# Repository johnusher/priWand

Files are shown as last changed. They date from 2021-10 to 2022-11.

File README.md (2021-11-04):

# priWand

# johnusher/priWand Summary

Private Repo! <br />
This repo is for the wand project. <br />

Mesh network between multiple Raspis for a nice game of Wand.

A webserver on the pi provides a bi-directional UI.

## Hardware set-up

Tested with Pi 4, 3B, Zero (they have the same GPIO pin out)

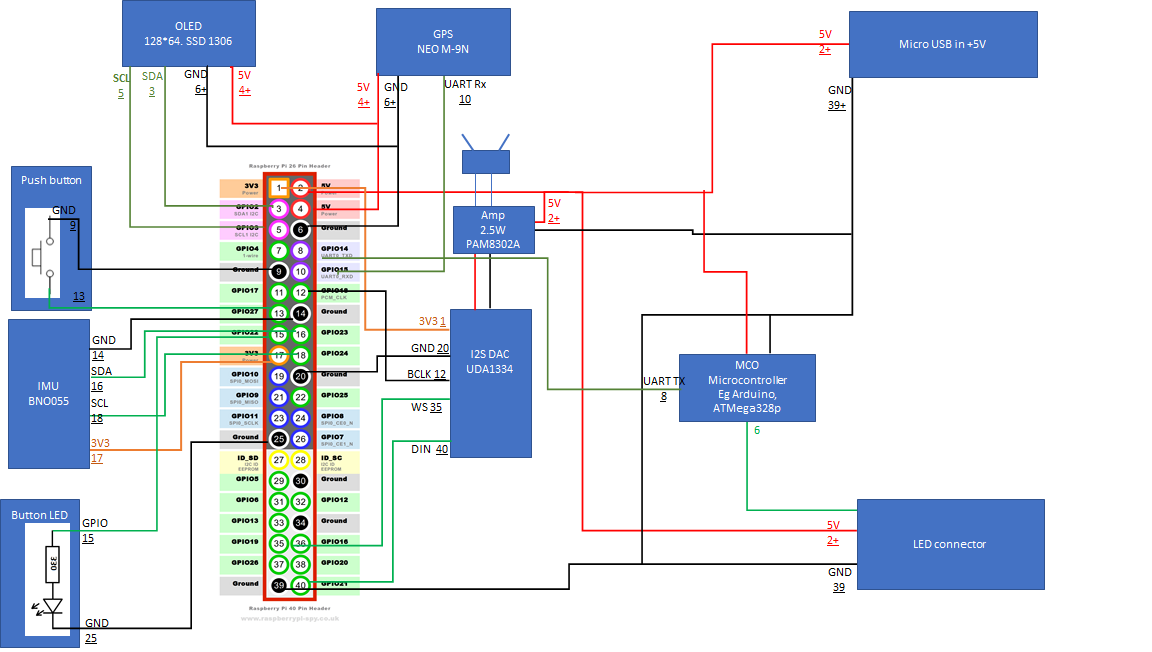
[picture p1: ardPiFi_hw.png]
HardWare


See [shopping list section](#hardware-shopping-list) for details on components. 

### MCU for programmable LEDs 
ATmega328p- Arduino Nano. MCU and NeoPixelLED strips should be powered separately.

### GPS
GPS module connect with GPIO serial. It shows up at serial port /dev/ttyS0. In raspi-config settings, you  need to disable serial console output, enable Hardware serial, and maybe disable bluetooth. 

Tested using the UBLOX NEO-6M (GPS only= less accurate) and NEO M-9N (GPS, GLONASS, Galileo = more accurate).

Note we only use serial Rx from GPS module into the Raspi, as we use Serial Tx for Arduino MCU.

NEO M-9N default 38000 baud UART, but changed to 9600 and poll every 2 seconds. To do this this, use u-center 21.02 (windows only), or use NEO9Settings.txt configuration script with ubxconfig.sh from https://gist.github.com/hdoverobinson/42732da4c5b50d031f60c1fae39f0720)  (untested and won't work without serial Tx from Raspi)

```bash
./ubxconfig.sh /dev/ttyS0 NEO9Settings.txt
```

Useful GPS:
```bash
go run gps/test_GPS2.go 
```

Prints Lat-Long cooridinates and HDOP.<br />
where HDOP:<br />
<1	Ideal	Highest possible confidence level to be used for applications demanding the highest possible precision at all times.<br />
1-2	Excellent	At this confidence level, positional measurements are considered accurate enough to meet all but the most sensitive applications.<br />
2-5	Good	Represents a level that marks the minimum appropriate for making accurate decisions. Positional measurements could be used to make reliable in-route navigation suggestions to the user.<br />
5-10	Moderate	Positional measurements could be used for calculations, but the fix quality could still be improved. A more open view of the sky is recommended.<br />

Read raw NMEA format GPS data from serial port
```bash
cat -A /dev/ttyUSB0
```

Write raw NMEA format data to file
```bash
cat </dev/ttyUSB0 > gpsdata.txt
```

Convert NMEA file to Google-maps kml, discard low-HDOP data that is not "excellent quality", dude.
```bash
gpsbabel -i nmea -f gpsdata.txt -x discard,hdop=1,sat=9  -o kml -F outfile.kml
```

### Audio: I2S

Raspi Zero does not have audio IO, so output is I2S into a 2 W amp, and then to a loudspeaker.

Install port audio and make I2s default:
```bash
sudo apt-get install libasound-dev portaudio19-dev libportaudio2 libportaudiocpp0 mpg123 
curl -sS https://raw.githubusercontent.com/adafruit/Raspberry-Pi-Installer-Scripts/master/i2samp.sh | bash
```
reboot.

Test audio works:

```bash
sudo speaker-test -c2 
sudo mpg123 -b 1024 http://ice1.somafm.com/u80s-128-mp3
```
to generate white noise out of the speaker, alternating left and right.

There is no built-in audio out with the Pi-Zero, so we use an I2S audio DAC: UDA1334.

from https://learn.adafruit.com/adafruit-i2s-stereo-decoder-uda1334a/raspberry-pi-wiring

Optional to remove ALSA errors:<br />
sudo vi /usr/share/alsa/alsa.conf to change pcm.front cards.pcm.front -> pcm.front cards.pcm.default<br />
Use the file alsa.conf in the git repo.

sudo apt-get --no-install-recommends install jackd2

### GPIO: Button and LED

A push button attaches to GPIO27=  pin 13, and an LED with 330 Ohm series resistor to GPIO22 =  pin 15.

GPIO support not intalled for Raspi Lite so run this:
```bash
sudo apt-get install wiringpi
gpio readall
```

on pi 4, try the following:

```bash
cd /tmp
wget https://project-downloads.drogon.net/wiringpi-latest.deb
sudo dpkg -i wiringpi-latest.deb
```

test button LED works:
```bash
gpio -g mode 22 out
gpio -g write 22 1
 ``` 
 
run this command to set pullup:
```bash
raspi-gpio set 27 pu
```

when you run
gpio readall
you should see following when button not pressed 
```bash
BCM| wPi |   Name  | Mode | V
27 |   2 | GPIO. 2 |   IN | 1 
```
```bash
27 |   2 | GPIO. 2 |   IN | 0
```
when pressed 

To test GPIO is working, run test_GPIO2.go (you will need I2S connected for audio)
```bash
run test_GPIO2.go
```

### Display screen
OLED 128*64.

Power with +5 V. OLED connects via I2C bus 1. SDA -> pin 3  SCL -> pin 5). 

### Inertial Measurement Unit (IMU)
Bosch BNO055:  triaxial accelerometer, gyroscope, geomagnetic sensor.

Power with +3.3 V.
connect BNO055 SDA to pin 16 and SCLK to pin 18.

I2c configure:

From https://github.com/kpeu3i/bno055/:

"it seems all versions of Raspberry Pi have an I²C bus hardware problem preventing them from working correctly with Bosch BNO055. The problem has been variously diagnosed as being due to the Pi’s inability to handle clock stretching in arbitrary parts of the I²C transaction and the BNO055 chip’s exquisite sensitivity to I²C bus levels."

Raspbian has a software I2C driver that can be enabled by adding the following line to /boot/config.txt:

dtoverlay=i2c-gpio,bus=3
This will create an I2C bus called /dev/i2c-3. SDA will be on GPIO23 and SCL will be on GPIO24 which are pins 16 and 18 on the GPIO header respectively.

SDA = pin 16, SCL = pin 18.

```bash
sudo tee --append /boot/config.txt > /dev/null << 'EOF'
dtoverlay=i2c-gpio,bus=3
EOF
```
++sudo reboot now

Check your I2c is set up correctly:

sudo apt-get install i2c-tools

sudo i2cdetect -l

You will now see that i2c bus 3 also listed. Also run:

sudo i2cdetect -y 1

This should show OLED on 3c

sudo i2cdetect -y 3

This should show the BNo055 on 28.

There are "no hardware" options for running the main Go file without these HW modules.

## WLAN dongle: 

Add USB dongle TP-Link TL-WN725N.

This messes up BATMAN as the dongle can go to WLAN0 or WLAN1.
To change this and make WLAN0 the built-in: see 

https://www.raspberrypi.org/forums/viewtopic.php?f=36&t=198946

1. switch off systemd-predictable mechanism stuff (unless done already):

```bash
sudo ln -nfs /dev/null /etc/systemd/network/99-default.link
  ```

  2. setup udev rules that uniquely identify your interfaces based on their USB connector positions:

```bash

vi /etc/udev/rules.d/72-wlan-geo-dependent.rules

#
# +---------------+
# | wlan1 | wlan1 |
# +-------+-------+
# | wlan1 | wlan1 |
# +---------------+ (RPI USB ports with position independent device names for a maximum of 1 optional wifi dongle)
# 
# | wlan0 | (onboard wifi)
#
ACTION=="add", SUBSYSTEM=="net", SUBSYSTEMS=="sdio", KERNELS=="mmc1:0001:1", NAME="wlan0"
ACTION=="add", SUBSYSTEM=="net", SUBSYSTEMS=="usb",  KERNELS=="1-1.2",       NAME="wlan1"
ACTION=="add", SUBSYSTEM=="net", SUBSYSTEMS=="usb",  KERNELS=="1-1.4",       NAME="wlan1"
ACTION=="add", SUBSYSTEM=="net", SUBSYSTEMS=="usb",  KERNELS=="1-1.3",       NAME="wlan1"
ACTION=="add", SUBSYSTEM=="net", SUBSYSTEMS=="usb",  KERNELS=="1-1.5",       NAME="wlan1"

 ```

NB

When running on WLAN1, we must force IP4 to access github.com as it does not support IP6

sudo dhclient -4 -v wlan1

or

```bash
sudo tee --append /etc/sysctl.conf > /dev/null << 'EOF'
net.ipv6.conf.all.disable_ipv6=1
EOF
 ```

echo sudo net.ipv6.conf.all.disable_ipv6=1 >> /etc/sysctl.conf

Install driver for tl-wn8725N

from:
https://www.raspberrypi.org/forums/viewtopic.php?p=462982#p462982
```bash
sudo wget http://downloads.fars-robotics.net/wifi-drivers/install-wifi -O /usr/bin/install-wifi
sudo chmod +x /usr/bin/install-wifi
sudo install-wifi
 ```
reboot

make sure you have added static ip to wlan 1:

```bash
sudo tee --append /etc/dhcpcd.conf > /dev/null << 'EOF'

# set static ip

interface wlan1
static ip_address=192.168.1.164/24
static routers=192.168.1.1
static domain_name_servers=192.168.1.1

EOF
 ```

after iwconfig
should see wlan0 and wlan connected to same ESSID with AP.

## Auto-start: 

Automatically load BATMAN ad the go script on boot.

To do this, we make a service. This runs on bootup, after the network is up. It runs runBATMAN.sh (or run runBATMAN2, runBATMAN3):

After 20 seconds, the BATMAN mesh network is generated, then the go app is run.

Thus, you need to make sure the app is pre-compiled,
ie
```bash
cd /home/pi/apl/
go build wand1.go
```

There are many ways to do this, but this one is mine. systemctl is not my best friend. For about an hour, it was my life. I do not care to master it.

1. cd ~/apl2

2. chmod 664 delayBoot2.service

3. sudo cp   delayBoot2.service  /etc/systemd/system/

4. sudo systemctl enable  delayBoot2

5. sudo systemd-analyze verify delayBoot2.service

To reload systemd with this new service unit file, run:
systemctl daemon-reload

To start the script on boot, enable the service with systemd:

6. sudo systemctl enable delayBoot2.service

useful:

sudo systemctl stop delayBoot2.service

sudo systemctl start delayBoot2.service

systemctl status delayBoot2.service

## Hardware shopping list

Rasperry Pi 3 Model B+ tested, Pi Zero WH, and Pi-4 B

MCU:
https://www.christians-shop.de/Nano-V3-developer-board-for-Arduino-IDE-ATMEL-ATmega328P-AVR-Microcontroller-CH340-Chip-Christians-Technikshop

https://www.amazon.de/-/en/gp/product/B078SBBST6/ref=ppx_yo_dt_b_asin_title_o02_s00?ie=UTF8&psc=1

GPS: uBlox NEO-6M :
https://www.amazon.de/dp/B088LR3488/ref=pe_3044161_185740101_TE_item

GPS: uBlox NEO-M9N :
https://tinyurl.com/j2476wb  (Banggood.com)

OLED display:
https://www.amazon.de/-/en/gp/product/B01L9GC470/ref=ppx_od_dt_b_asin_title_s00?ie=UTF8&psc=1

IMU Bosch BNO055:
https://www.amazon.de/-/en/gp/product/B072NLTPTJ/ref=ppx_yo_dt_b_asin_title_o01_s00?ie=UTF8&psc=1

BROgrammable LED strip WS2812:
https://www.mouser.de/ProductDetail/digilent/122-000/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

WLAN dongle TP-Link TL-WN725N:
https://www.amazon.de/gp/product/B008IFXQFU/ref=ppx_yo_dt_b_asin_title_o03_s00?ie=UTF8&psc=1

### OS

Install Raspi lite from onlione or try this:

1. Download Raspian Lite: https://downloads.raspberrypi.org/raspbian_lite_latest
2. Flash `20XX-XX-XX-raspbian-stretch-lite.zip` using Etcher
3. Remove/reinsert flash drive
4. Add `ssh` and `bootstrap` files:
    ```bash
    touch /Volumes/boot/ssh
    cp bin/bootstrap /Volumes/boot/
    chmod a+x /Volumes/boot/bootstrap
    diskutil umount /Volumes/boot
    ```

### First Boot

```bash
ssh pi@raspberrypi.local
# password: raspberry

# change default password
passwd

# set quiet boot
sudo sed -i '${s/$/ quiet loglevel=1/}' /boot/cmdline.txt

# install packages
sudo apt-get update
sudo apt-get install -y git tmux vim dnsmasq hostapd

# set up wifi (note leading space to avoid bash history)
sudo tee --append /etc/wpa_supplicant/wpa_supplicant.conf > /dev/null << 'EOF'
network={
    ssid="<WIFI_SSID>"
    psk="<WIFI_PASSWORD>"
}
EOF

# set static IP address
sudo tee --append /etc/dhcpcd.conf > /dev/null << 'EOF'

# set static ip

interface eth0
static ip_address=192.168.1.164/24
static routers=192.168.1.1
static domain_name_servers=192.168.1.1

interface wlan0
static ip_address=192.168.1.164/24
static routers=192.168.1.1
static domain_name_servers=192.168.1.1

EOF

if we have an additional wlan usb:

sudo tee --append /etc/dhcpcd.conf > /dev/null << 'EOF'

# set static ip

interface wlan1
static ip_address=192.168.1.164/24
static routers=192.168.1.1
static domain_name_servers=192.168.1.1

EOF

# reboot to connect over wifi
sudo shutdown -r now
```

```bash
# configure git
git config --global push.default simple
git config --global core.editor "vim"
git config --global user.email "you@example.com"
git config --global user.name "Your Name"

# disable services
sudo systemctl disable hciuart
sudo systemctl disable bluetooth
sudo systemctl disable plymouth

# remove unnecessary packages
sudo apt-get -y purge libx11-6 libgtk-3-common xkb-data lxde-icon-theme raspberrypi-artwork penguinspuzzle ntp plymouth*
sudo apt-get -y autoremove

sudo raspi-config nonint do_boot_behaviour B2 0
sudo raspi-config nonint do_boot_wait 1
sudo raspi-config nonint do_serial 1
```

# now you are setup! run bootstrap to download packages

Run Bootstrap from https://github.com/johnusher/ardpifi/tree/master/bin
./bootstrap
```

### Mesh network

NB need to runt his command twice!

On raspi #1 run

./runBATMAN.sh

On raspi #2 run

./runBATMAN2.sh

## Code

Note
All dependencies managed in `go.mod` now,
just add an import directive for any new depedency in your `*.go` files, and
`go run/build` should just handle it.

All code (and go) is installed via bootstrap.

# Arduino CLI install

follow instructions here:
https://siytek.com/arduino-cli-raspberry-pi/

this additional command was needed:
arduino-cli core install arduino:avr

Note the directory for the Duino project must have the same name as the main file .ino.

Tested with Duino Uno and Duino clone: "Nano V3 | ATMEL ATmega328P AVR Microcontroller | CH340-Chip".
The Uno shows on port ttyACM0 and the clone on ttyUSB.

## add libraries:

arduino-cli lib search Adafruit_NeoPixel

in duino_src:

compile and flash:
Uno:
arduino-cli compile --fqbn arduino:avr:uno duino_src

arduino-cli upload -p /dev/ttyACM0 --fqbn arduino:avr:uno duino_src

Clone

arduino-cli compile --fqbn arduino:avr:diecimila:cpu=atmega328 duino_src

arduino-cli upload -p /dev/ttyUSB0 --fqbn arduino:avr:diecimila:cpu=atmega328 duino_src

arduino-cli upload -p /dev/ttyACM0 --fqbn arduino:avr:diecimila:cpu=atmega328 duino_src

## Run

On raspi #1 run

```bash
./runBATMAN.sh
go run wand1.go -rasp-id=me --web-addr :8080 -log-level debug
```

On raspi #2 run

```bash
./runBATMAN2.sh
go run wand1.go -rasp-id=poo --web-addr :8081 -no-lcd -log-level debug.
```

Press any key, sent to mesh, and if it is a 0 or 1, we change led pattern.

To exit, press "q" to exit termbox, and then ctrl-c to exit the program.

### Flags

There are various flags if certain HW modules are not attached to the raspi:

```bash
$ go run wand1.go -h
  -log-level string
    	log level, must be one of: panic, fatal, error, warn, info, debug, trace (default "info")
  -no-batman
    	run without batman network
  -no-duino
    	run without arduino
  -no-gps
    	run without gps
  -no-acc
    	run without Bosch accelerometer      
  -no-oled
    	run without oled display      
  -no-oled
    	run without sound  
  -rasp-id string
    	unique raspberry pi ID (default "60"). Only 2 characters. Recomended to use last 2 digits of the device IP.
  -web-addr string
    	address to serve web on (default ":8080")
```

### Run without hardware

Run with hardware (serial, network) API calls mocked out:

```bash
go run wand1.go --rasp-id "raspi 1" --web-addr :8080 --no-batman --no-duino --no-gps --no-lcd --log-level debug
```

# Set up port forwarding for web server

## First-time ssh config setup

On laptop:

```bash
PI_IP=192.168.1.164
USER=pi

cat << EOF >> ~/.ssh/config

Host pi
  HostName $PI_IP
  User $USER
  Port 22
  BatchMode yes
  ServerAliveInterval 60
  ServerAliveCountMax 5
  ForwardAgent yes
    LocalForward 127.0.0.1:8080 127.0.0.1:8080
EOF
```

## Tunnel

```bash
ssh $USER@pi
```

Open a browser window to localhost:8080

## Main routines to run:

```bash
go build test_record_spell.go && sudo ./test_record_spell -no-sound
```
test_record_spell records MCU movement when we have a button press.

NB The GPIO channel can not close properly, so you may need to kill the app with

sudo ps aux | grep test_record_spell

kill -9 -1 3290 

## Other useful scripts
```bash
go run test_BNo055_save_data.go
```
NB not running!! This saves accelerometer and gyroscope data to a txt file.

```bash

go build test_GPIO.go && sudo ./test_GPIO

```
NV this currently fails! This reads the button, debounces, and plays sound when we have button down.

```bash
go run OLEDtest.go
```
This displays a real-time clock on the OLED.

```bash
go run test_quats_64_to_py_tf.go
```
process quat recordings with TF... this tests if you have python and go correctly installed.

```bash
go run test_parse_quats_oled.go
```
test_parse_quats_oled

convAccData.m

MATLAB script to process accelerometer data.

# thanks 

@siggy!

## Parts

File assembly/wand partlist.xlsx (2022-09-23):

item | cost |  | order
loudspeaker | 2.6 | x | for 2. https://www.berrybase.de/raspberry-pi/raspberry-pi-computer/displays/8-ohm-5w-lautsprecher-passend-f-252-r-waveshare-displays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
audio amp | 4.05 |  | https://www.berrybase.de/sensoren-module/audio-schall/adafruit-mono-2.5w-class-d-audio-verst-228-rker-pam8302
small button+LED | 3.95 | x | https://www.amazon.de/-/en/gp/product/B07SR4S6MS/ref=ewc_pr_img_1?smid=A3B8GCWPRWBH74&psc=1
Pi Zero | 11.13 | g
ATmega328p | 3.7 | g
OLED | 6.99 |  | https://www.az-delivery.de/en/products/0-96zolldisplay
GPS |  | g
IMU | 34.16 |  | https://www.exp-tech.de/sensoren/magnet/8435/bluedot-bno055-9-axis-imu
PLED | 5 |  | https://www.led-genial.de/Power-Dot-3W-WS2811-kompatibel
I2S Audio | 7.15 |  | https://www.berrybase.de/sensoren-module/audio-schall/adafruit-i2s-stereo-decoder-uda1334a-breakout
Micro USB connector | 0.79 | g | https://www.amazon.de/dp/B07W13X3TD?ref_=pe_27091401_487187591_302_E_DDE_dt_1
I2S+3W | 6.15 | x | https://www.berrybase.de/sensoren-module/audio-schall/adafruit-i2s-3w-class-d-verst-228-rker-breakout-max98357a
pi connector
 | 85.67

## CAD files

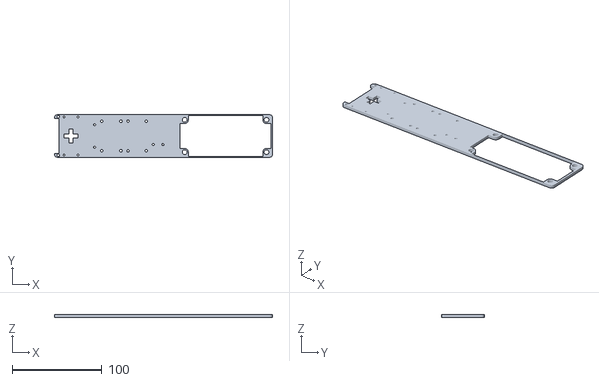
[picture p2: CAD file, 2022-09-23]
assembly/3d print iteration 1/3d print iteration 1/Mid Enclosure.STL
242.4 x 47.4 x 3.00

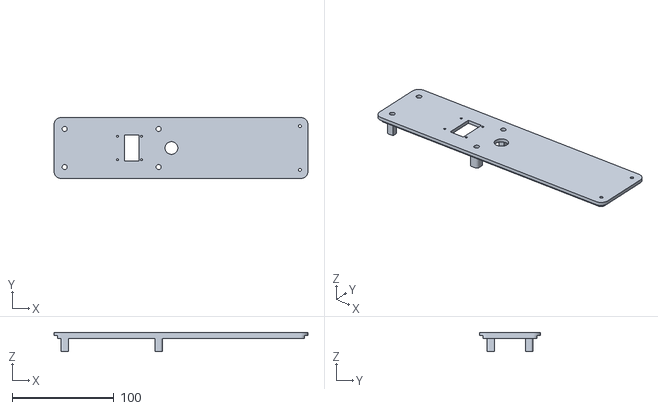
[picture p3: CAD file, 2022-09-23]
assembly/Iteration2/iteration 2 stls/Top Enclosure.STL
250.0 x 60.0 x 19.0

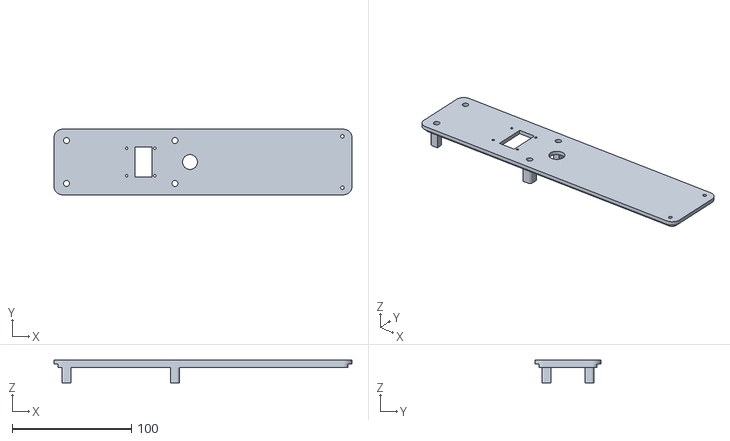
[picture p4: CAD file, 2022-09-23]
assembly/3d print iteration 1/3d print iteration 1/Top Enclosure.STL
250.0 x 55.0 x 19.0

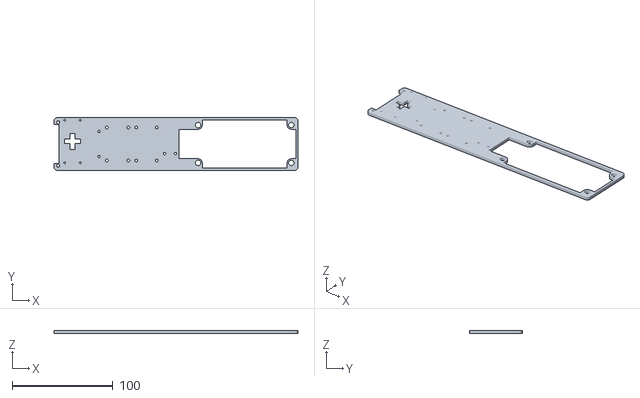
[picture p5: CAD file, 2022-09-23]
assembly/Iteration2/iteration 2 stls/Mid Enclosure.STL
242.4 x 52.4 x 3.00

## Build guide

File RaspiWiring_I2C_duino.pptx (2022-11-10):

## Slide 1

OLED
128*64. SSD 1306

GPS
NEO M-9N

UART TX
8

5V
2+

Micro USB in +5V

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
UART Rx
10

GND
39+

Amp
2.5W
PAM8302A

I2S DAC
UDA1334

5V
2+

Button

9

13

Aduino Nano
SDA = A4
SCL = A5

IMU
BNO055

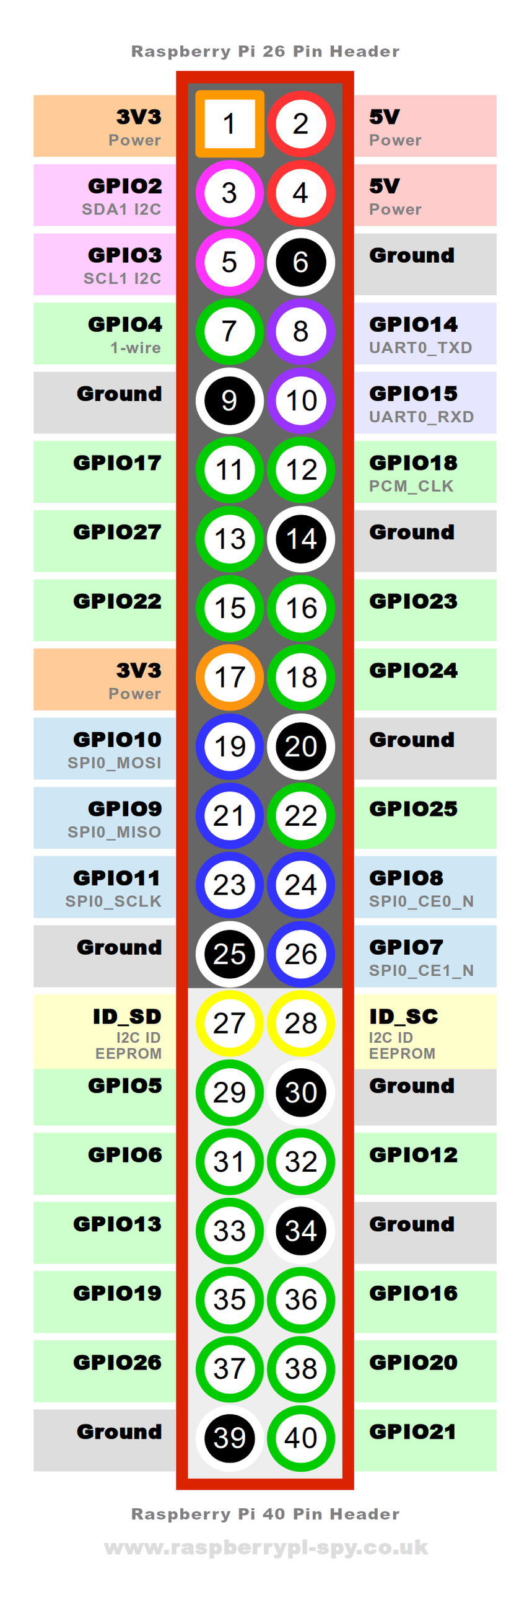
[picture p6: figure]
Simple Guide to the Raspberry Pi GPIO Header - Raspberry Pi Spy

GND
14

GND 20

3V3 1

SDA
16

SCL
18

BCLK 12

WS 35

Aduino Nano

3V3
17

DIN 40

6

Button LED

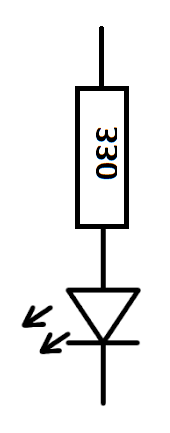
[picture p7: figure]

GPIO
15

5V
2+

LED connector

GND
39

GND
25

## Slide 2

OLED
128*64. SSD 1306

GPS
NEO M-9N

5V
2+

Micro USB in +5V

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
UART Rx
10

GND
39+

Push button

GND
9

13

5V
2+

I2S DAC+amp
MAX98357

IMU
BNO055

GND
14

SDA
16

SCL
18

BCLK 12

WS 35

UART TX
8

MCO
Microcontroller
ATMega328p

3V3
17

DIN 40

6

Button LED

GPIO
15

5V
2+

LED connector

GND
39

GND
25

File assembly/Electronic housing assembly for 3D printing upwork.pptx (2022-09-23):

## Electronic housing assembly for 3D printing

John Usher
15-Mar-22

## Overview

- Design CAD for 3D printing an assembly to house 11 electronic components.
- Outer dims of unit is cuboid and approx. 55x210x40 mm.
- Comprises:
  - 1. Lower box (5 sides)
  - 2. Centre plate.
  - 3. upper plater.
- Electronic boards are mounted using screws.
- Box should be approx. 3 mm thick.
- Delivery are files suitable for 3D printing the components.

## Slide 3

100 x 45 x 21mm

End view:

27x27

OLED

40x25

Button
33 mm O

I2S audio

30x19

45x17.5

32x25

Screw holes

Loudspeaker

GPS

IMU

ATmega

PLED

Screw holes to attach top plate with case

LED

Just two tiny holes for LED legs (eg 1 mm)

Pi-Zero: 66.0mm x 30.5mm: should be offset to allow access to USB

PLED mounts on to this plate

Micro USB connector at case end

Same height as OLED

OLED

GPU antenna

Upper face

Middle layer of box:
has mounting holes for all
except Pi-Zero

Lower face

Loudspeaker

button

Pi Zero

PLED

PLED on its edge
LED of PLED though hole in end plate

Pi-Zero screws on to case bottom

Loudspeaker drivers face down into air gap (5 mm)

Vent slots below loudspeaker for sound: eg 5 slots, 4 mm width, 30 mm length

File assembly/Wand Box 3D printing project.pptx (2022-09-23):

## Wand Case Protype

John Usher
24-Mar-22

## Overview

- Design CAD for 3D printing an assembly to house 11 electronic components.
- Outer dims of unit is cuboid and approx. 55x210x40 mm.
- Comprises:
  - 1. Lower box (5 sides)
  - 2. Centre plate.
  - 3. upper plater.
- Electronic boards are mounted using screws.
- Box should be approx. 3 mm thick.
- Delivery are files suitable for 3D printing the components.

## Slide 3

100 x 45 x 21mm

30x19

27x27

OLED

24x15

Button
33 mm O

40x25

I2S audio

45x17.5

32x25

Screw holes

Loudspeaker

amp

GPS

IMU

ATmega

PLED

Screw holes to attach top plate with case

LED

Hole for LED in top plate and middle plate

Hole for antenna wires

Pi-Zero: 66.0mm x 30.5mm: should be offset to allow access to USB

PLED mounts on to this plate

Micro USB connector at case end

Same height as OLED

OLED

GPU antenna

Pi Zero

Upper face

Middle layer of box:
has mounting holes for all
except Pi-Zero

Lower face

Loudspeaker

button

PLED

PLED on its edge
LED of PLED though hole in end plate

Pi-Zero screws on to case bottom

Loudspeaker drivers face down into air gap (5 mm)

Vent slots below loudspeaker for sound: eg 5 slots, 4 mm width, 30 mm length

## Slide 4

WIRING

30x19

24x15

Button
33 mm O

40x25

I2S audio

45x17.5

32x25

Loudspeaker

OLED

amp

GPS

IMU

ATmega

PLED

LED

GPU antenna

Loudspeaker

OLED

button

Pi Zero

PLED

## Amp

- https://www.reichelt.de/de/en/developer-boards-audio-amplifier-class-d-pam8302a-debo-sound-amp1-p235505.html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
- 24 x 15 x 2 mm
- Class D audio amp

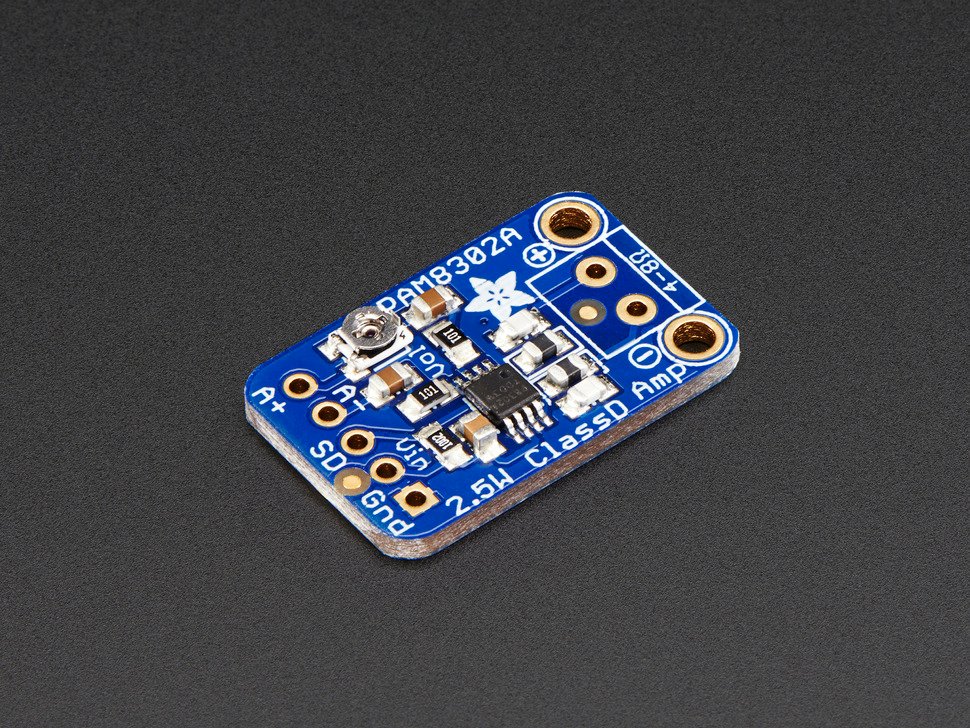
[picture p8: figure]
Angled shot of Adafruit Mono 2.5W Class D Audio Amplifier.

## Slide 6

LARGE Button:

https://www.ozstick.com.au/information/useful-product-info/

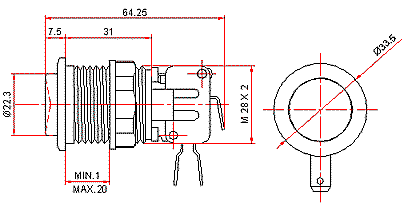
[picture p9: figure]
Classic Dimpletop button schematic

Diameter of screw thread = ???
Hole in top plate should ideally have screw thread, if not, then make slightly larger and will just glue in place to hold.

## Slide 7

- https://www.amazon.de/-/en/gp/product/B07XJY4VBQ/ref=ppx_yo_dt_b_search_asin_title?ie=UTF8&th=1

SMALL Button:

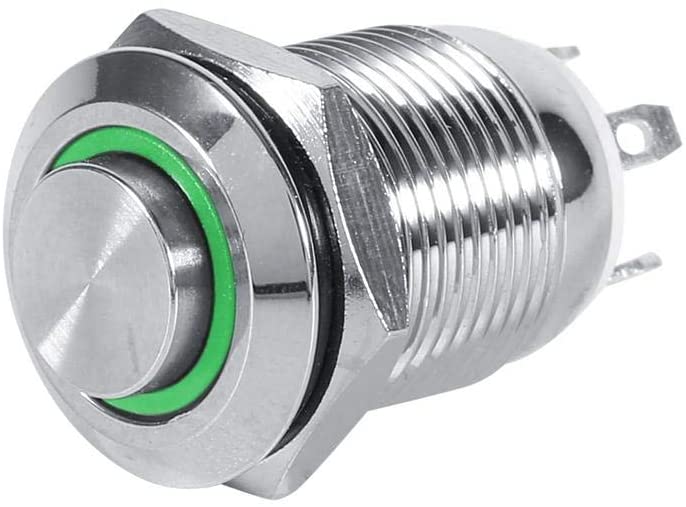
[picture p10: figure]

## Loudspeaker

- https://www.berrybase.de/raspberry-pi/raspberry-pi-computer/displays/8-ohm-5w-lautsprecher-passend-f-252-r-waveshare-displays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
- 100 x 45 x 21mm
- Note 4 corner screw-holes are half-way in height

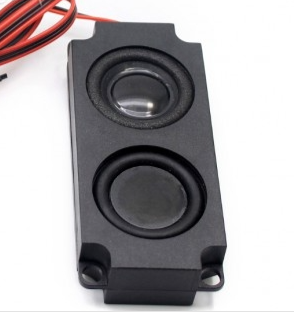
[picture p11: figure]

## Pi Zero

- 66.0mm x 30.5mm x 5.0mm

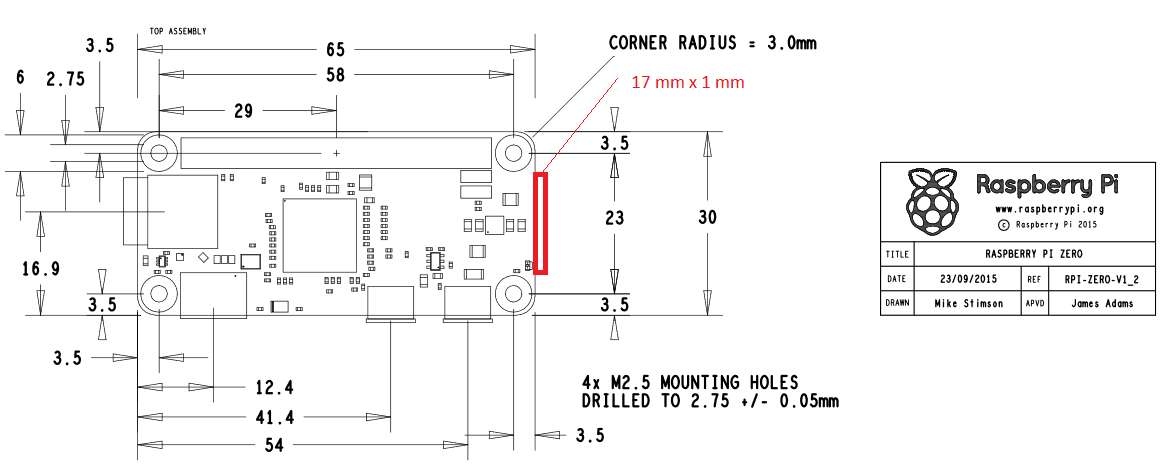
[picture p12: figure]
pi zero - What should be the dimension of the cases that are used for Pi-Zero1.3? - Raspberry Pi Stack Exchange

Board should be offset to give access to USB ports

## ATmega328p

- https://www.amazon.de/-/en/gp/product/B0755XYBG4/ref=ppx_yo_dt_b_search_asin_image?ie=UTF8&th=1
- 45 x 17,5 x 18 mm

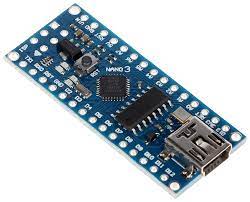
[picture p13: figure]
MODUL NANO-V3/CH340 - Symbolgeneratoren (OSD) - Delta

## OLED

- OLED Display I2C 128 x 64 Pixel I2C
- https://www.az-delivery.de/en/products/0-96zolldisplay

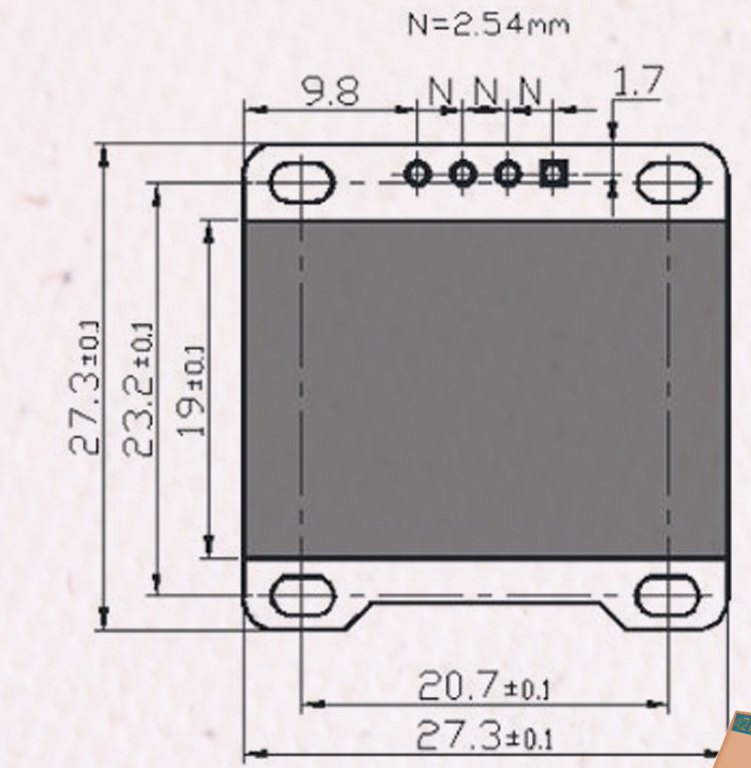
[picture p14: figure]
0.96″ OLED Display I2C/IIC/TWI 128×64 Punkte Anzeige:hellblau Module für Arduino | 42project.net
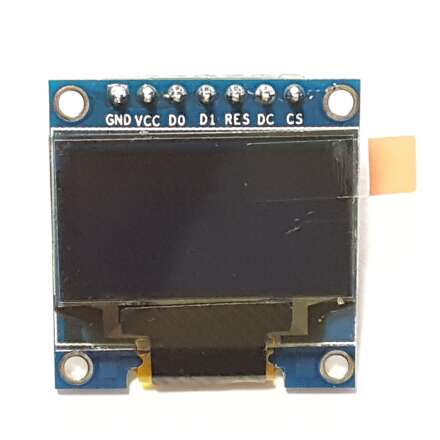
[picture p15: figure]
0,96" OLED Display Blau/Gelb I2C SPI 128x64 SSD1106 für Arduino Raspberry Pi, 4,

## GPS

- NEO M-9N
- https://www.amazon.de/dp/B088LR3488?ref_=pe_3044161_248799201_302_E_DDE_dt_1
- NB is board and patch antenna.
- Board = 26x36mm
- Patch antenna = 25x25 mm

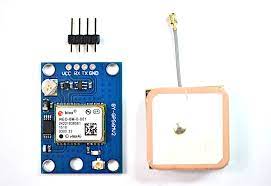
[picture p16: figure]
NEO-6M GPS Module — Maker Portal

## IMU

- https://www.bluedot.space/products/bno055/
- 30*19*2 mm (NB connector pins are approx 4 mm)

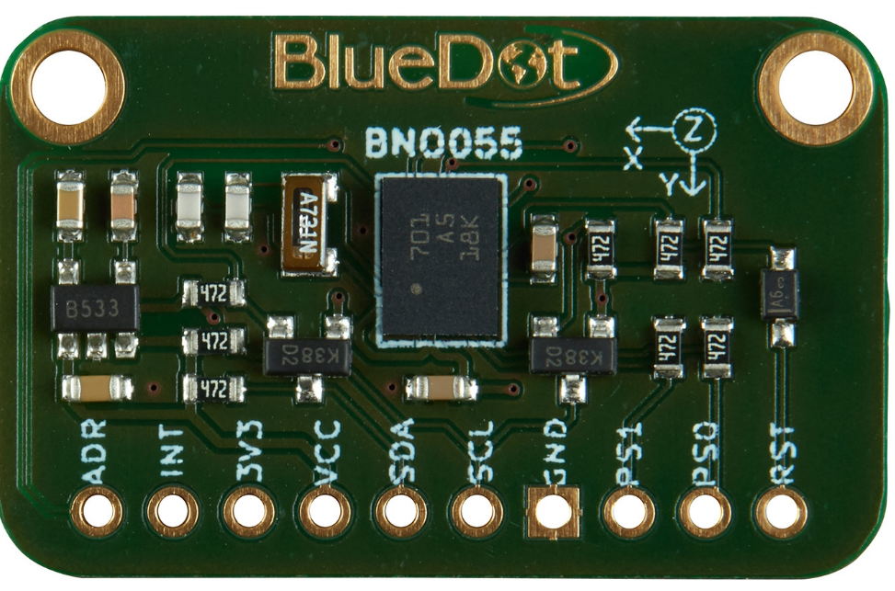
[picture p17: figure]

Mounting holes

## PLED (Programmable LED)

- Power-Dot 3W, WS2811
- https://www.led-genial.de/Power-Dot-3W-WS2811-kompatibel
- 32 x 25mm

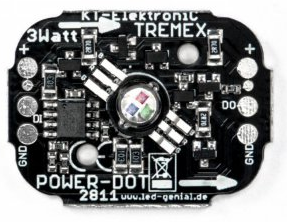
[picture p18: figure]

Mounting holes

## I2S Audio

- Adafruit I2S Stereo Decoder - UDA1334A
- https://www.adafruit.com/product/3678
- Product Dimensions: 40.0mm x 25.0mm x 7.1mm

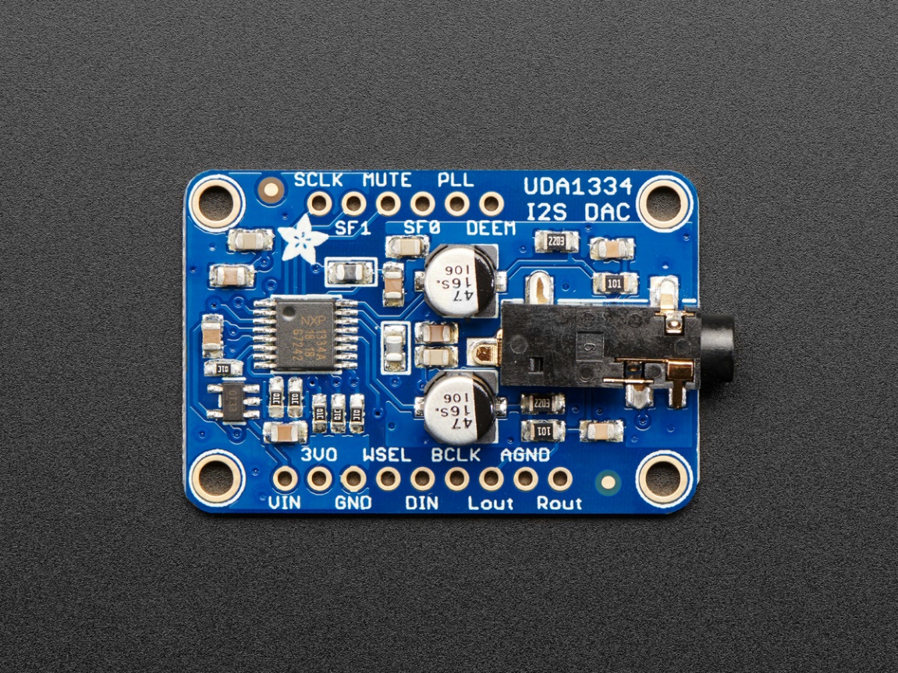
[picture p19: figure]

## Micro USB connector

- https://www.amazon.de/dp/B07W13X3TD?ref_=pe_27091401_487187591_302_E_DDE_dt_1
- 10 x 5 x 0.5 cm

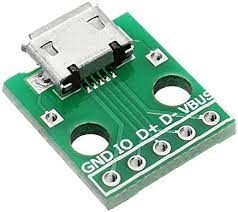
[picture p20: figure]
ILS - 10 Pieces Micro USB to Dip Female Socket B Type Microphone 5P Patch to Dip 2.54mm Pin with Soldering Adapter Board: Amazon.de: Elektronik & Foto

## Standard LED

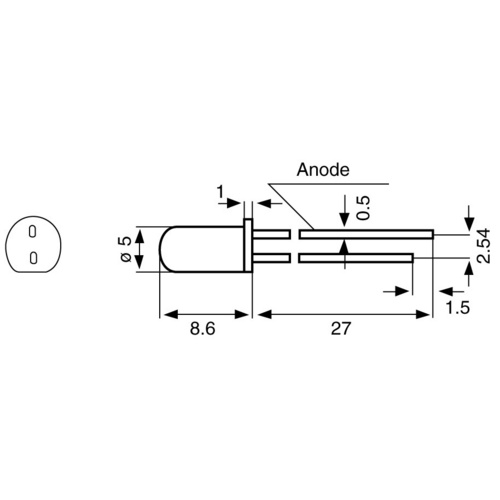
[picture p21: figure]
LED Wired Yellow Round 5mm 60° 8.5mA

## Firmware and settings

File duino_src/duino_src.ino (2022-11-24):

/**
  Arduino code:
  For single programmable LED
  receive message on I2C and serial USB and change LED

  To program ATmega328P:
  Select "Arduino Duemilanove and proc 328P

  serial messages should be semi-colon delimited

  first value is mode
  mode 0 = solid [g r b]   eg 0;20;40;100 [serial]  or 00 14 28 64 [i2c]
  mode 1 = flash [g r b onTime offTime] eg 1;64;20;5;100;100 [serial]  or 01 40 14 05 64 64 [i2c]
  mode 2 = random [not quite working]
  mode 3 = rainbow fade,  second argument should be 25 for fast fade
  mode 5 = program flash [g r b N onTime1 offTime1 ... onTimeN offTimeN] eg 5;64;20;5;3;100;100;200;200;300;300

  mode 9 = set brightness (right shift amount of GRB) eg 9;2

*/

//#include <Boards.h>
//#include <Firmata.h>
//#include <FirmataConstants.h>
//#include <FirmataDefines.h>
//#include <FirmataMarshaller.h>
//#include <FirmataParser.h>

#include <Wire.h>   // I2C

#include "ard_JU.h"

#include "Adafruit_NeoPixel.h"   // from https://github.com/adafruit/Adafruit_NeoPixel

Adafruit_NeoPixel strip = Adafruit_NeoPixel(nLEDS, ledPin, NEO_GRB + NEO_KHZ800);

void setup() {
  pinMode(ledPin, OUTPUT);
  strip.begin();
  //  myStripShow(); // Initialize all pixels to 'off'
  // Serial.begin(9600);
  // Serial.begin(19200);
  Serial.begin(115200);
  Wire.begin(I2C_SLAVE_ADDRESS);                // join i2c bus with address #2
  Wire.setWireTimeout( 250, true);   // 1000 µs is 1 ms timeout
  Wire.setClock(400000);  // kHz

  Wire.onRequest(requestEvents); // register event
  Wire.onReceive(receiveEvents);
  //  idleCol =  strip.Color(ColG, ColR, ColB);
}

/**
   Main Arduino loop.
*/
void loop() {

  while (Serial.available() == 0) {
    strip.setPixelColor(0, 255 >> brightness, 0, 0);
    strip.show();

    for (i = 0; i < 65530; i++) {
      checkSerialInput();
    }
    strip.setPixelColor(0, 0, 255 >> brightness, 0);
    strip.show();

    for (i = 0; i < 65530; i++) {
      checkSerialInput();
    }

    strip.setPixelColor(0, 0, 0, 255 >> brightness);
    strip.show();

    for (i = 0; i < 65530; i++) {
      checkSerialInput();
    }
  }

}


void requestEvents()
{
  Serial.println(F("---> recieved request"));
  Serial.print(F("sending value : "));
  Serial.println(53);
  Wire.write(53);
}

void receiveEvents(int numBytes)
{
  //  Serial.println(F("---> recieved events"));
  int byte1I2C = Wire.read();

  if (byte1I2C == -1) {
    //    empty
    Serial.println(F("i2cRx empty"));
    return;

  }
  //  Serial.println(F("i2cRx empty"));
  //  Serial.println(numBytes);

  data[0] = byte1I2C;

  for (j = 1; j < numBytes; j++) {

    data[j] = Wire.read();
    //    Serial.println(data[j] );

  }




  if (data[0] == 0) {
    Mode = 0;
    //    Serial.println("Mode 0");
    mode0();
  }

  if (data[0] == 1) {
    Mode = 1;
    mode1();
  }

  if (data[0] == 2) {
    Mode = 2;
    mode2();
  }

  if (data[0] == 3) {
    Mode = 3;
    mode3();
  }

  if (data[0] == 5) {
    Mode = 5;
    mode5();
  }


  if (data[0] == 9) {
    Mode = 9;
    mode9();
  }

  return;



}


void checkSerialInput() {

  // expect a strong like 0,1,123,456,789*

  //  https://forum.arduino.cc/t/split-string-by-delimiters/373124/3

  //  or here:
  //  https://forum.arduino.cc/t/splitting-up-a-string-with-a-delimiter-and-storing-each-cut-in-an-array/628574

  // input message is delimited with semi colon and termniated with newline
  // must begin with a 0

  //  idle_flag = 0;
  //  strip.clear();
  serial_in = Serial.read();


  if (serial_in == -1) {
    //    empty
    return;

  }

  serialResponse = Serial.readStringUntil('\r\n');
  //  Serial.println(serialResponse);

  // Convert from String Object to String.
  char buf[sizeof(sz)];
  serialResponse.toCharArray(buf, sizeof(buf));
  char *p = buf;
  char *str;

  //   Serial.println(buf);
  //  Serial.println(sizeof(buf));

  i = 1;
  while ((str = strtok_r(p, ";", &p)) != NULL) { // delimiter is the semicolon
    //        Serial.println(str);
    strings[i] = str;
    i = i + 1;
  }
  i = i - 1;

  //  Serial.println("i:");
  //  Serial.println(i);

  for (j = 1; j < i + 1; j++) {
    //      Serial.println("j:");
    data[j] = String(strings[j]).toInt();
    //    Serial.print("a:");
    //        Serial.println(strings[j] );
    //    Serial.print("b:");
    //    Serial.println(data[j] );
    //    Serial.println();
  }

  if (serial_in == '0') {
    Mode = 0;
    mode0();
  }

  if (serial_in == '1') {
    Mode = 1;
    mode1();
  }

  if (serial_in == '2') {
    Mode = 2;
    mode2();
  }

  if (serial_in == '3') {
    Mode = 3;
    mode3();
  }

  if (serial_in == '5') {
    Mode = 5;
    mode5();
  }


  if (serial_in == '9') {
    Mode = 9;
    mode9();
  }

  return;

}

void mode0() {

  //  Serial.println(data[1]);
  //  Serial.println(data[2]);
  //  Serial.println(data[3]);
  //  Serial.println(brightness);
  //  Serial.println("mode 0");
  // solid

  ColR = data[1] ;
  ColG = data[2] ;
  ColB = data[3] ;

  while (Serial.available() == 0) {

    strip.setPixelColor(0, ColG >> brightness, ColR >> brightness, ColB >> brightness);
    strip.show();

    for (i = 0; i < 65530; i++) {
      checkSerialInput();
    }

  }

}

void mode1() {
  //  Serial.println("mode 1");

  //  Serial.println(data[1]);
  //  Serial.println(data[2]);
  //  Serial.println(data[3]);
  //  Serial.println(data[4]);
  //  Serial.println(data[5]);
  //  Serial.println(brightness);
  //  Serial.println("mode 1");

  // flash (blink, on/off)

  ColR = data[1] ;
  ColG = data[2] ;
  ColB = data[3];

  onTime = data[4];
  offTime = data[5];

  while (Serial.available() == 0) {

    //    Serial.println(brightness);
    //    Serial.println("");


    //    Serial.print("ColG:");
    //    Serial.println(ColG);
    //     Serial.print("ColR:");
    //    Serial.println(ColR);
    //     Serial.print("ColB:");
    //    Serial.println(ColB);

    strip.setPixelColor(0, ColG >> brightness, ColR >> brightness, ColB >> brightness);
    strip.show();

    for (i = 0; i < onTime; i++) {
      for (j = 0; j < onTime; j++) {
        checkSerialInput();
      }
    }

    strip.setPixelColor(0, 0, 0, 0);
    strip.show();

    for (i = 0; i < offTime; i++) {
      for (j = 0; j < offTime; j++) {
        checkSerialInput();
      }
    }

  }

}


void mode5() {
  //  mode 5 = program flash [g r b N onTime1 offTime1 ... onTimeN offTimeN] eg 5;64;20;5;3;100;100;200;200;300;300
  //eg 5;64;20;5;2;100;100
  //eg 5;64;20;5;3;100;100;200;200
  //eg 5;64;20;5;4;100;100;200;200;300;300
  //eg 5;64;20;5;5;100;100;200;200;300;300;400;400

  //  Serial.println(data[1]);
  //  Serial.println(data[2]);
  //  Serial.println(data[3]);
  //  Serial.println(data[4]);
  //  Serial.println(data[5]);
  //  Serial.println(brightness);
  //  Serial.println("mode 5");

  // flash (blink, on/off)

  ColR = data[1] ;
  ColG = data[2] ;
  ColB = data[3];

  nBlinks = data[4];

  //    Serial.println("x");
  //    Serial.println(data[5]);
  //    Serial.println(data[6]);
  //
  //    Serial.println(data[7]);
  //    Serial.println(data[8]);
  //
  //    Serial.println(data[9]);
  //    Serial.println(data[10]);


  //   Serial.println(nBlinks);

  while (Serial.available() == 0) {

    for (ll = 0; ll < nBlinks; ll++) {

      //        Serial.println("x");
      //        Serial.println(ll);
      //        Serial.println(data[5+2*ll]);
      //        Serial.println(data[5+2*ll+1]);

      onTime = data[5 + 2 * ll];
      offTime = data[5 + 2 * ll + 1];

      strip.setPixelColor(0, ColG >> brightness, ColR >> brightness, ColB >> brightness);
      strip.show();

      for (i = 0; i < onTime; i++) {
        for (j = 0; j < onTime; j++) {
          checkSerialInput();
        }
      }

      strip.setPixelColor(0, 0, 0, 0);
      strip.show();

      for (i = 0; i < offTime; i++) {
        for (j = 0; j < offTime; j++) {
          checkSerialInput();
        }
      }

    }

  }

}


void mode2() {
  //  Serial.println("mode 2");
  // flash random
  onTime = data[1];
  offTime = data[2];

  while (Serial.available() == 0) {

    for (k = 1; k < 97; k++) {
      ColR = (k & 1) << 16;
      ColG = (k & 2) << 8;
      ColB = k & 4 << 4;
      strip.setPixelColor(0, ColR >> brightness, ColG >> brightness, ColB >> brightness);
      strip.show();
      for (i = 0; i < onTime; i++) {
        for (j = 0; j < onTime; j++) {
          checkSerialInput();
        }
      }
      strip.setPixelColor(0, 0, 0, 0);
      strip.show();
      for (i = 0; i < offTime; i++) {
        for (j = 0; j < offTime; j++) {
          checkSerialInput();
        }
      }
    }
  }
}

void mode3() {
  //  Serial.println("mode 3");
  // fade rainbow
  // second argument should be 25 for fast fade

  onTime = data[1];
  while (Serial.available() == 0) {

    for (int k = 0; k < 360; k++)
    {
      trueHSV(0, k);

      for (i = 0; i < onTime; i++) {
        for (j = 0; j < onTime; j++) {
          checkSerialInput();
        }
      }
    }
  }

}

void mode9() {
  //  Serial.println("mode 9: adjust brightness");

  brightness = data[1];

  //  Serial.println(brightness);
  //   Serial.println(Mode);
  //  Serial.println();

  if (Mode == 0) {
    //    Serial.println(Mode);
    Mode = 0;
    mode0();
  }

  if (Mode == 1) {
    Mode = 1;
    mode1();
  }

  if (Mode == 2) {
    Mode = 2;
    mode2();
  }

  if (Mode == 3) {
    Mode = 3;
    mode3();
  }

  return;

}


// the real HSV rainbow
void trueHSV(byte LED, int angle)
{
  byte red, green, blue;

  if (angle < 60) {
    red = 255;
    green = HSVlights[angle];
    blue = 0;
  } else if (angle < 120) {
    red = HSVlights[120 - angle];
    green = 255;
    blue = 0;
  } else if (angle < 180) {
    red = 0, green = 255;
    blue = HSVlights[angle - 120];
  } else if (angle < 240) {
    red = 0, green = HSVlights[240 - angle];
    blue = 255;
  } else if (angle < 300) {
    red = HSVlights[angle - 240], green = 0;
    blue = 255;
  } else
  {
    red = 255, green = 0;
    blue = HSVlights[360 - angle];
  }
  setRGBpoint(red, green, blue);
}

void setRGBpoint(uint8_t red, uint8_t green, uint8_t blue)
{
  // this code is for common anode LEDs. If you use common cathode ones,
  // remove the '255-' bits.
  //  analogWrite(outputPins[LED*3], 255-red);
  //  analogWrite(outputPins[LED*3+1], 255-green);
  //  analogWrite(outputPins[LED*3+2], 255-blue);

  strip.setPixelColor(0, green >> brightness, red >> brightness, blue >> brightness);
  strip.show();
}

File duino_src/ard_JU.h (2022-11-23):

#ifndef _ARD_JU_ACH_
#define _ARD_JU_ACH_

const byte nLEDS = 1;
const byte ledPin = 6;

int serial_in;
int Mode = 0;

# define I2C_SLAVE_ADDRESS 42

//int i2cRx = 0;
String i2cRx = "";
String serialResponse = "";
char sz[] = "1; 2; 3;4;5;6.414;7;8;9;10;11;12;13;14;15;16;17;19";

char binary[3] = {0}; //This is where the binary representation will be stored
byte someValue = 1; // we loop over 3 bits

//char array[] = "0;123;456;789";

int data[32];

char *strings[14];
char *ptr = NULL;

//int ind1; // , locations
//int ind2;
//int ind3;
//int ind4;

String readString; //main captured String 
String code;
String data1;

int idleC = 0;	// counter for led position
int colC = 0;	// counter for led colour


uint8_t ColR = 64; 	// colour of idle
uint8_t ColG = 32; 
uint8_t ColB = 49; 
uint8_t nBlinks = 1; 

uint8_t brightness = 4;   // amount we right shift by

uint16_t onTime = 5000; 
uint16_t offTime = 5000; 

uint8_t maxC = 128;   // max colour value

bool idle_flag = 1; 



int breakFlag = 0; 

uint16_t i, j,k,ll;	

// for rainbow effect:
const uint8_t HSVlights[61] = 
{0, 4, 8, 13, 17, 21, 25, 30, 34, 38, 42, 47, 51, 55, 59, 64, 68, 72, 76,
81, 85, 89, 93, 98, 102, 106, 110, 115, 119, 123, 127, 132, 136, 140, 144,
149, 153, 157, 161, 166, 170, 174, 178, 183, 187, 191, 195, 200, 204, 208,
212, 217, 221, 225, 229, 234, 238, 242, 246, 251, 255};




#endif

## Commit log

2021-11-06 wand1 send button
2021-11-06 only zap if button down and pointing
2021-11-08 IMU calibration test
2021-11-08 calibration offsets
2021-11-08 calibrate for 3 secs
2021-11-08 print buttonStatus
2021-11-09 listen for button message
2021-11-09 init buttonStatus
2021-11-09 ButtonStatus init
2021-11-11 use single power-dot LED
2021-11-13 default IMU direction is along X axis, P0
2022-02-09 adding i2c to imu package
2022-02-12 record IMU data with button ctl
2022-03-20 housing CAD upwork ppt
2022-03-24 assembly info
    [Mid Enclosure.STL, Top Enclosure.STL, wand partlist.xlsx]
2022-03-29 step files
    [wand partlist.xlsx]
2022-09-09 iteration 2 CAD
    [Mid Enclosure.STL, Top Enclosure.STL]
2022-09-24 tone play with pitch mapped to tilt
2022-09-27 print bmp working
2022-10-03 IMU to image parsing to work on Raspi OLED
2022-10-03 convert IMU file to OLED for Raspi
2022-10-03 OLED IMU parser working well
2022-10-04 reorient IMU for better results
2022-10-08 save bmp of image after imu gesture
2022-10-08 image save updates on board
2022-10-09 testing IMU
2022-10-27 IMU data
2022-11-01 plot bearing roll tilt
2022-11-10 duino connects with I2C and serial
2022-11-23 I2C still hangs
2022-11-24 I2C write now working to control PLEDs
2022-11-29 IMU giving relative quats, no magnet reading
